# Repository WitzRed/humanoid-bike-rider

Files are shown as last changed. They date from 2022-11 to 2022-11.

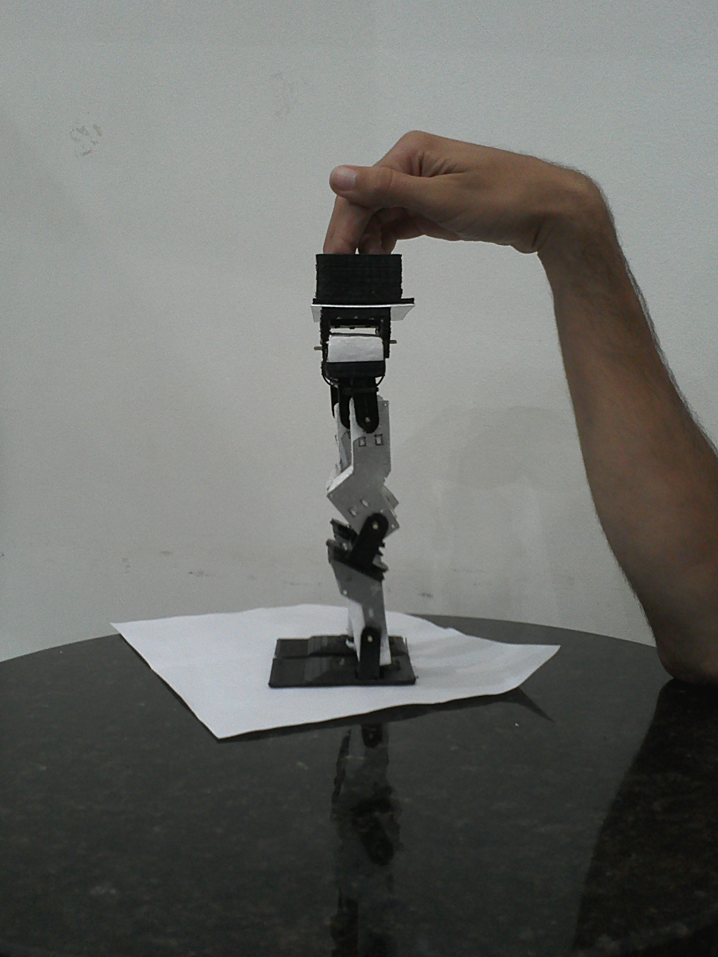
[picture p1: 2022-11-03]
src/paper/assets/CAM00465.jpg

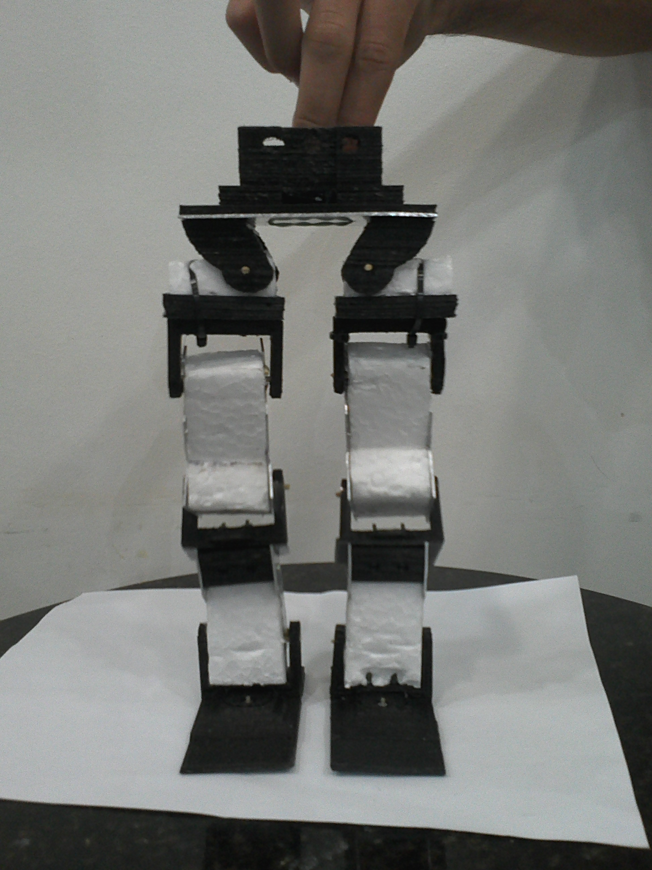
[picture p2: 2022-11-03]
src/paper/assets/CAM00467.jpg

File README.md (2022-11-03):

# humanoid-bike-rider
This project Includes the materials create for the developement of our humanoid bike rider.

https://www.scitepress.org/Papers/2019/77739/77739.pdf

Please use the following citation:

    @inproceedings{
        gorte2019modeling,
        author    = {Jo{\~{a}}o Martin Gorte Jr. and
               Witenberg Santiago Rodrigues Souza and
               Artur Benevenutto Coelho and
               L{\'{\i}} Exequiel E. L{\'{o}}pez},
          editor    = {Oleg Gusikhin and
               Kurosh Madani and
               Janan Zaytoon}, 
          title     = {The Modeling, Construction and Test Process of a 3D Printable Smart
               Robot Rider},  
          booktitle = {Proceedings of the 16th International Conference on Informatics in
               Control, Automation and Robotics, {ICINCO} 2019 - Volume 1, Prague,
               Czech Republic, July 29-31, 2019},   
          pages     = {165--172},
          publisher = {SciTePress},
          year      = {2019},
          url       = {https://doi.org/10.5220/0007773901650172},
          doi       = {10.5220/0007773901650172}
    }

Check out our demonstraion videos:

3D Prinable Humanoid Rider #1
https://www.youtube.com/watch?v=2ANicbNcGmM

First time testing 3D Printable Humanoid Rider #2
https://www.youtube.com/watch?v=PAA-fIjbb9Q

Testing 3D Printable Humanoid Rider #3
https://www.youtube.com/watch?v=QIu-1OhEkto

We thank "Dr. Guero" for his great insights:
https://www.youtube.com/user/DrGuero2001

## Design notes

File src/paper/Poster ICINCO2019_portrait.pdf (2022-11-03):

# The Modeling, Construction and Test Process of a 3D Printable Smart Robot Rider

# João Martin Gorte Jr.¹, Witenberg Santiago Rodrigues Souza

2

# , Artur Benevenutto Coelho

# 3 and Lí Exequiel E. López

3
1Department of Electrical Engineering, Higher Education Institute of Brasilia, L2 Sul, Brasilia, Brazil

# 2Postgraduate Program in Mechatronic Systems, University of Brasilia, Brasilia, Brazil

3Department of Computer Engineering, Higher Education Institute of Brasilia, Brasilia, Brazil

# {xrjunior, wittenberg.rsg}@gmail.com, artur-bc@hotmail.com, lopez@iesb.br

Methodology

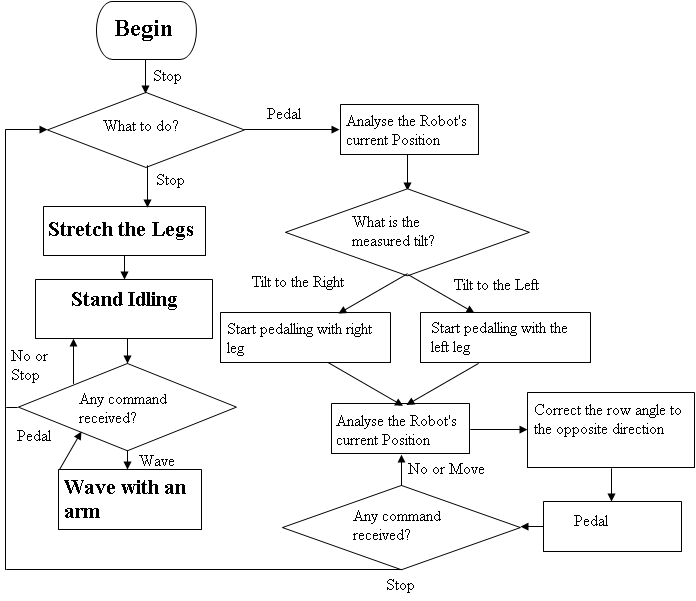
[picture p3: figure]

Results

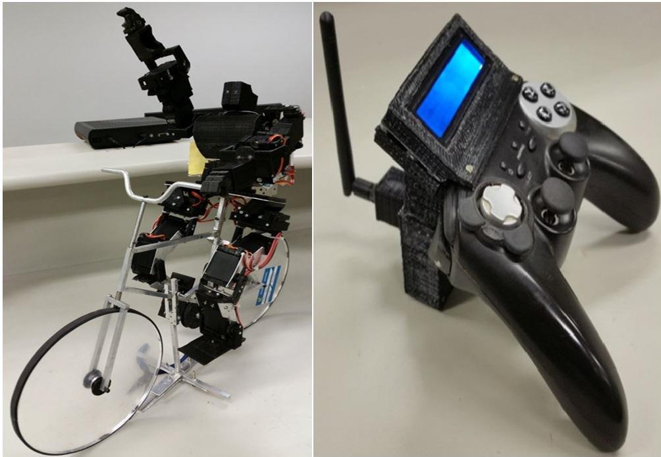
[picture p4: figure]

Conclusion

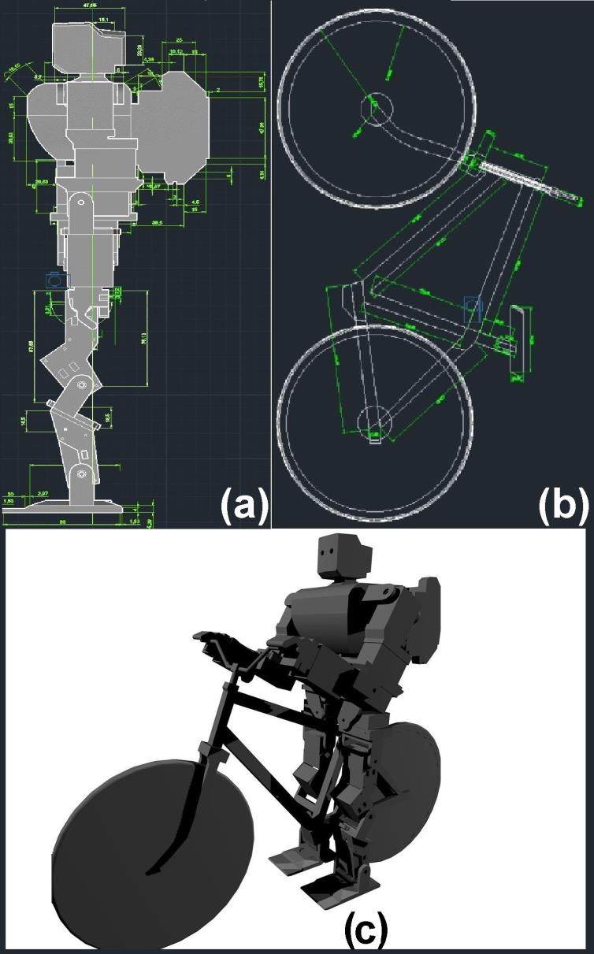
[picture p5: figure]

Introduction

Acknowledgments

Abstract
This work aims to present a modeling procedure, manufacturing process, electronic design, programming and communication system of a cyclist robot. The robot rider has the ability to ride a bicycle independently by making decisions on shifts in balance that may occur during its motion by correcting its direction, balance adjust, and stop. Robot decision-making processes were embedded in a shared control system of interactions with the external environment by commands sent through wired serial link or radio frequency (RF), allowing arm and leg- movements. This
was | achieved | using | a | dual | board
synchronization | powered | by | Atmel
microcontrollers (Arduino) and fed by information from an electronic gyroscope sensor, an accelerometer, and remote radio frequency (RF) receptor. The final prototype was able to pedal from inertia accelerating gradually to its full speed, stop the movement, and move its arms to recover balance.

The possibilities of autonomous bicycles and self-controlled or shared controlled robots able to maneuver vehicles have been explored for years (Getz and Marsden, 1995; Buss, 2000). It can be considered a theme driven by urban mobility needs, reduction of human physical effort and aiding people with disabilities. Moreover, modern urban mobility demands echo applications also motivate the green solution for living in large cities. Thus, increasing capacity of robots moving similarly to humans is essential for this purpose.

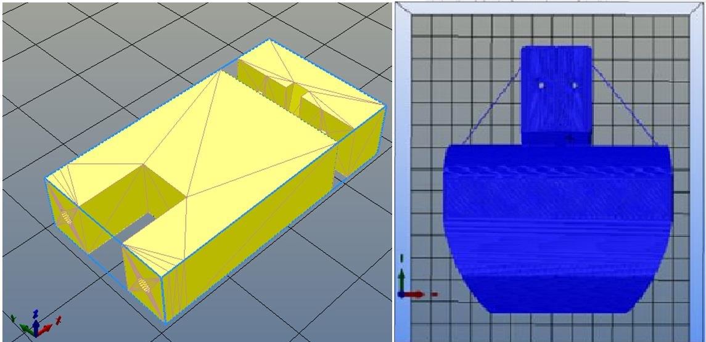
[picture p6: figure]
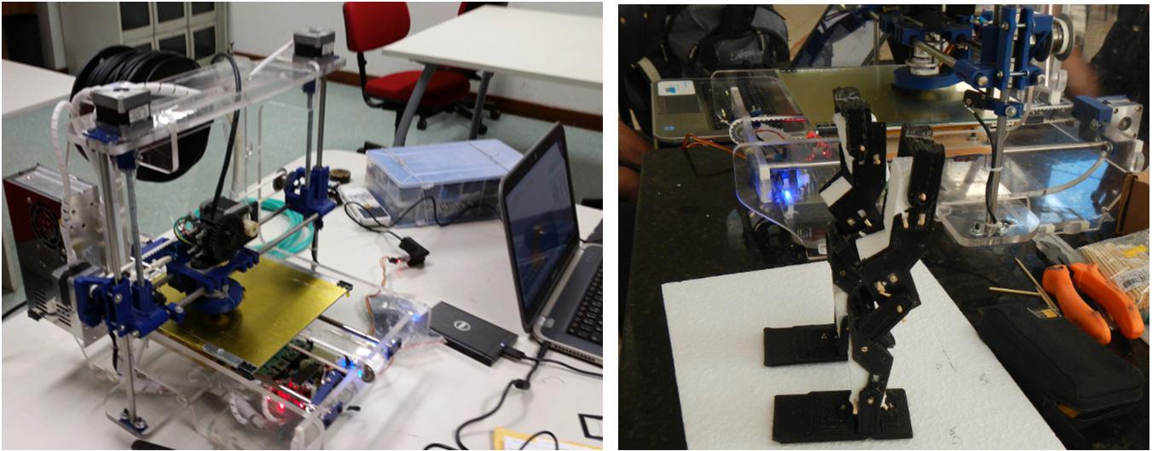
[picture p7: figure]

One of the main goals in Robotics is the automation of tasks done by men (Pazos, 2013). Thus, one of the goals in the field of Robotics is to perform simulation of variety of movements,
decision | making, | hence | human | tasks
performance. Despite intense research activity, large scale implementation of such tasks for daily life routine were not feasible in the early robotics, due to high cost and early development of auxiliary technology, causing to the field a moderate development outside of industrial applications.

Moreover, development of such robotic systems a requires multidisciplinary knowledge. This
work | involved | mathematical | modeling,
mechanical drawing, manufacture techniques in 3D printing, electronic design, micro-controller programming (Arduino, 2015; Banzi, 2013) as well as access to auxiliary devices including gyroscope, accelerometer, and RF system.

Simulation and Tests
Legs were tested to check their movement while pedaling. Tests had shown a balanced structure and well synchronized servomotors. After first tests, current measurements had shown consumption of 1.2A for each leg, in which every servomotor consumed 400mA. On a standby state the robot consumed 370mA. The first pedaling movement had to have fine tuning on tilt coupling, angular speed on each servomotor and low rotation setup to perform the desired movement.

This work presented the process of modeling, design, construction and test of 3D printable robot rider. The algorithm developed in C++ enable robot to move its arms and legs to perform desired actions such as pedaling, turning direction bar, start, and stop movements. The mathematical model proved to reach the proposed movement, although it required fine tuning to smooth the movement. All parts of the bike rider were designed to fit the servomotors. In order to a better performance, a second Arduino board had to be added to split the movements from legs to arms. Future work will include a free run test without a tripod that supported the initial test of the robot. Moreover, a forward kinematic system based on neural network can also be compared to the current algorithm.

The authors would like to thank the Institutional
Program | for | Initiation | in | Technological
Development and Innovation scholarship (PIBITI-CNPq) and the Scientific Initiation Program at the Higher Education Institute of Brasilia- IESB. The authors also would like to thank Dr. Masahiko Yamaguchi (Dr. Guero) and Christina Driessen for their wonderful ideas.

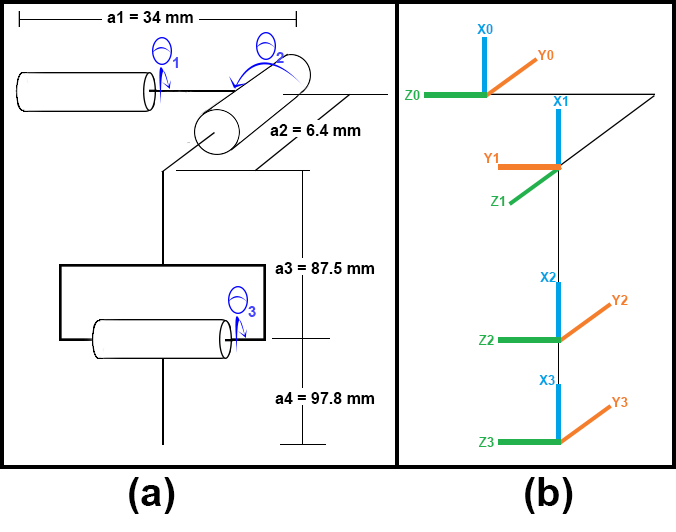
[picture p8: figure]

The algorithm cost required two Arduino boards (salver and master) to split the legs routines from the signals to the arms. A status signal allows the master to know if the other Arduino is on stop mode, movement, or whether an error occurred. Moreover, the master board also receives the remote commands from the joystick. When the system is ready, the master Arduino set all initial parameters on the slaver board to avoid code redundancy. After all parameters set, the slaver board flags back a ready signal to the master board.

The communication between both Arduinos allows the master to send stimuli signals to the slaver board when it is in movement mode. When it is in stop mode however, the master board sends only one stop signal. If the master board stops working and the salver board is in movement mode, as it will not receive the next stimuli, the emergency mode will be triggered when the time for the next stimulus is over. On the other hand, if the slaver Arduino board stops working, the master board will notice it by the status signal as it stopped receiving from the salver board. Therefore, the master board will immediately reset its own status and will keep trying to reestablish the link with the other board until it succeed. After reestablishing the link, the master board sends again the initial parameters to the salver board.

Assembled Final Prototype
The assembled prototype is shown on Figure 7. All 3D printed parts are in black as well as the servomotors. The bicycle is mainly made of aluminum bars and the wheels are made of acrylic. Next to the robot is the RF controller which was partially manufactured in the 3D printer. The controller is used to send the commands to set which movements the robot must perform.

The initial phase was the creation of mathematical models for arms and legs. The final step involved the simulation of movements for arms and legs as well as the first real world test for a pedal movement and balance. The construction of the robot was designed upon the use of renewable materials such as plastic which reduced the manufacturing cost. The same plastic was also used to built the 3D printer which has refurbished pass-motors. Moreover, discarded pieces of aluminum compose the frame of the bicycle and
the side shields on the legs of the robot.

Figure 1: Arm kinematic diagram: (a) link lengths in mm (a1 to a4) and rotation angles, b) four rotation frames for each actuator.

Figure | 2: | Leg | kinematic
diagram: c) link lengths and rotation angles, d) rotation frames.

Figure 4: Parts in the printing process servo’s socket on the left and the slicing process on the right.

Figure 3: Robot
(a) and its bicycle
(b) both sketched in AutoCAD,
(c) 3D model.

Modeling each 3D Part

Figure 5: Algorithm’s flowchart demonstrating the decision steps the robot may take.

Process of 3D printing

The majority of the parts of the robot (approximately 70%) were made by 3D printing. The 3D printers were also assembled using reusable materials. It works with plastic wires (3 mm or 1.75mm) made of polylactic acid (PLA) which is melted to make the layers of the 3D printed parts. After every part was finished by the printer, it was measured in order to check if its dimensions would met the designed project. Symmetry, and layer size were measured. Some parts which should be coupled to servomotor had density increased by 90% in order to bear forces applied to them. Other parts were redesigned for their size were not feasible to be printed as a single piece or they had inner connections that would not able accessed such as chest, battery case, and head). Because of lack of precision for small parts, some parts had to be adapted, such as the hands.

Figure 6: Printer and the first prototype printed legs.

The Assembling Process
A total 15 servo motors of 13N each with were used to move all members of the robot. This phase involved 40% of the project budget. The servo motor were also disassembled to add a 3mm steel axis to the opposite side the servo axis.

The bicycle assembling
In the process of construction of the bicycle, we used a 5mm solid aluminum bar to let the robot lighter and balance the weight / power ratio. TIG welding was used to reinforce the frame and with center of gravity for the suitable robot. The wheels are made of acrylic of 10 mm which were cut using the laser process to stay closer to the CAD model. After the assembling phase was complete, the prototype, as well as its remote control, as shown in 7, were ready for testing.

Figure 8: Foot movement simulation based on hip-to-foot displacement vector.

Figure 9: Movement for the palm of the hand resulted from the transformation by shoulder-to-hand displacement vector.

Figure 7: Assembled robot (second prototype) and joystick remote control.

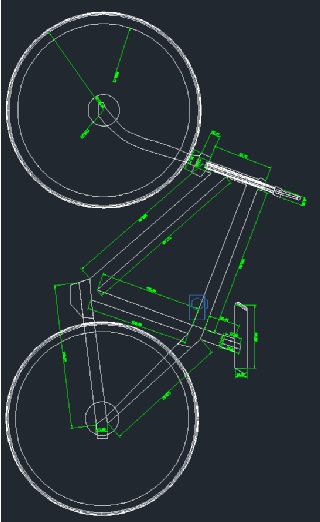
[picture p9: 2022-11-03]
src/paper/assets/bicycle2D.jpg

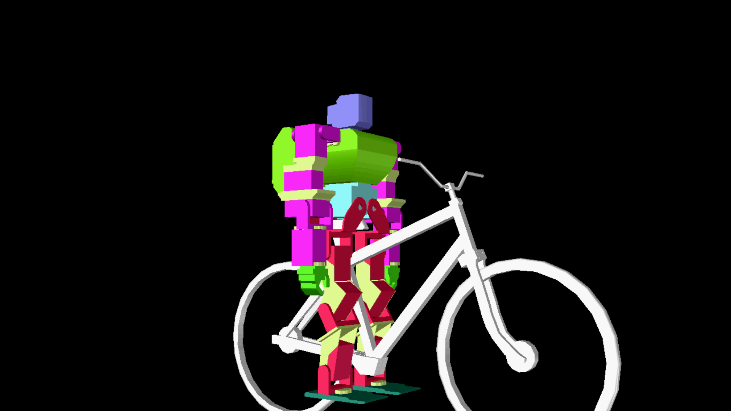
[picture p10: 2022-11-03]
src/paper/assets/robo_de_bike.png

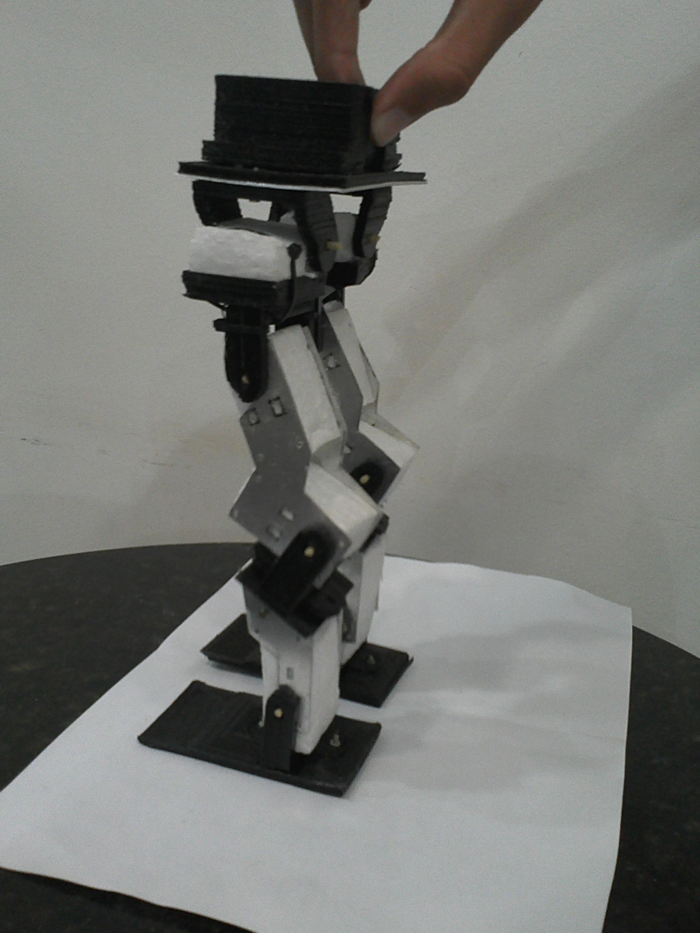
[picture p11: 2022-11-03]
src/paper/assets/CAM00469.jpg

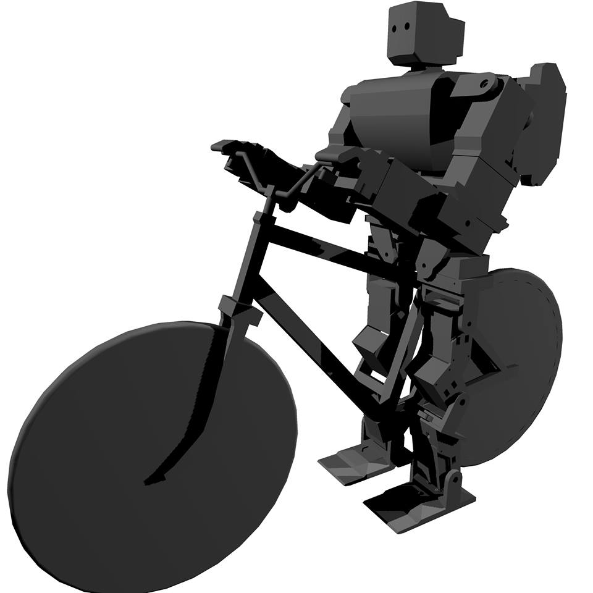
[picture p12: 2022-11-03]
src/paper/assets/Robot.jpg

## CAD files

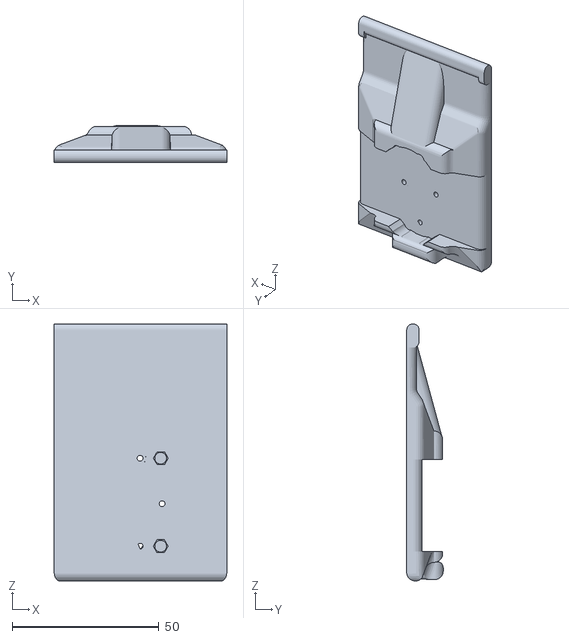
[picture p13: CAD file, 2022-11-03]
src/3d-modeling/DWG_PROJECT/novoPE.stl
58.8 x 12.5 x 87.6

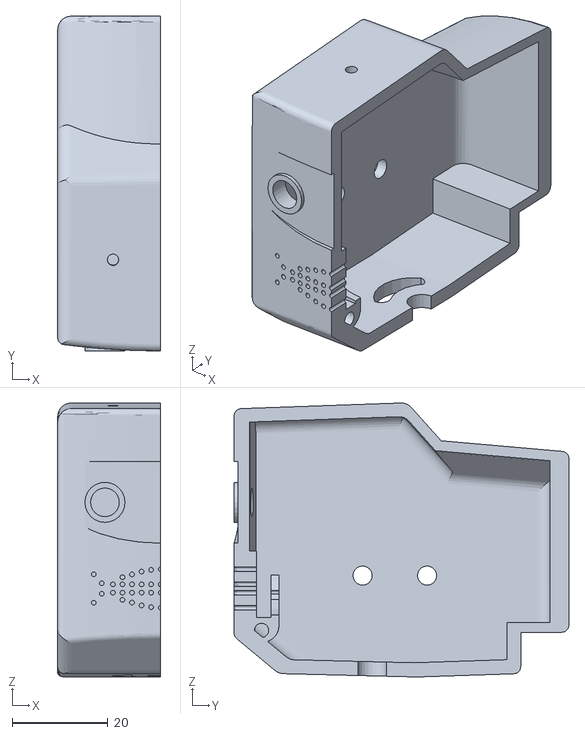
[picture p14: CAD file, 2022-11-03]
src/3d-modeling/DWG_PROJECT/ROBOT_v2017/AUTOCAD/RIGHT_HEAD_ROBOT_RIDER_07_5_2017.stl
21.5 x 70.1 x 57.4

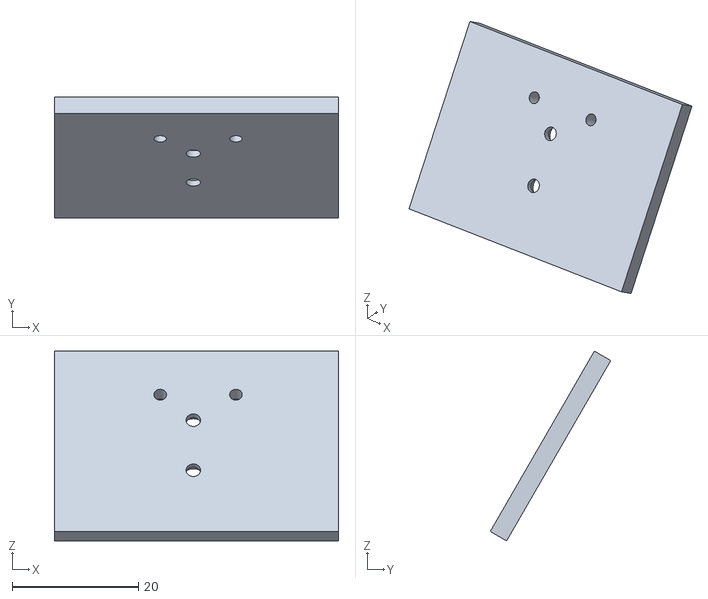
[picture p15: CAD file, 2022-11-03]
src/3d-printing/PARTS_STL/ACRYLIC_KNEE.stl
45.0 x 19.1 x 30.1

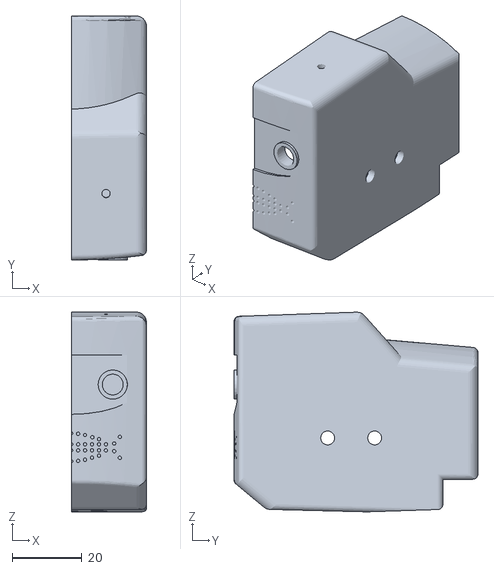
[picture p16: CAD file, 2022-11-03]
src/3d-modeling/DWG_PROJECT/ROBOT_v2017/AUTOCAD/LEFT_HEAD_ROBOT_RIDER__07_5_2017.stl
21.5 x 70.1 x 57.4

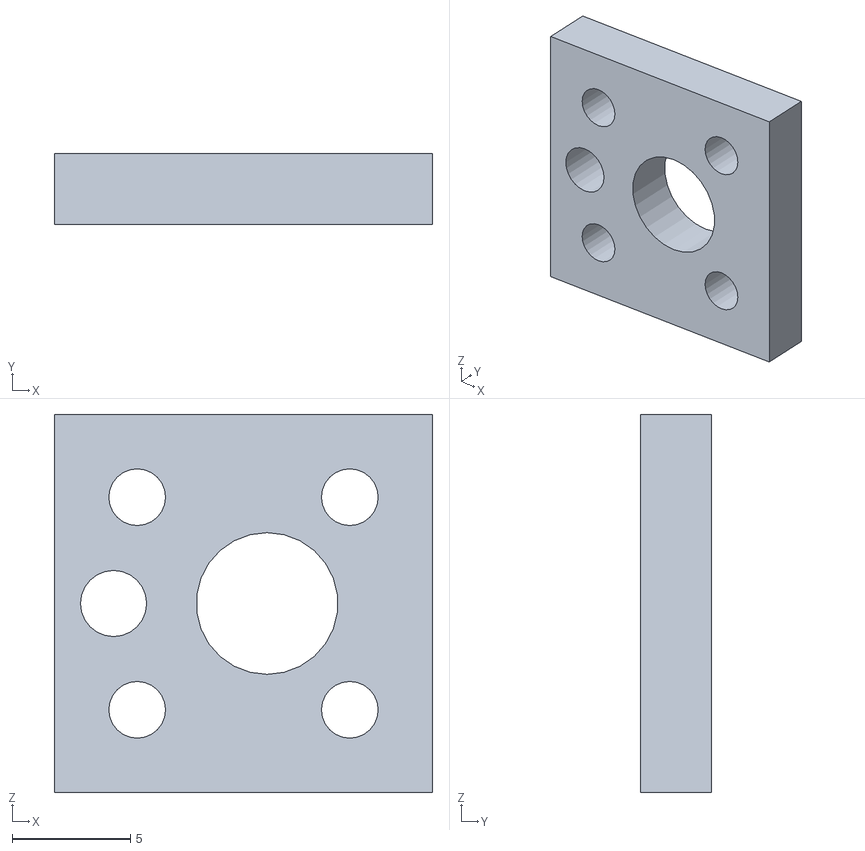
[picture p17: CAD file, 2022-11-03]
src/3d-printing/PARTS_STL/NECK.stl
16.0 x 3.00 x 16.0

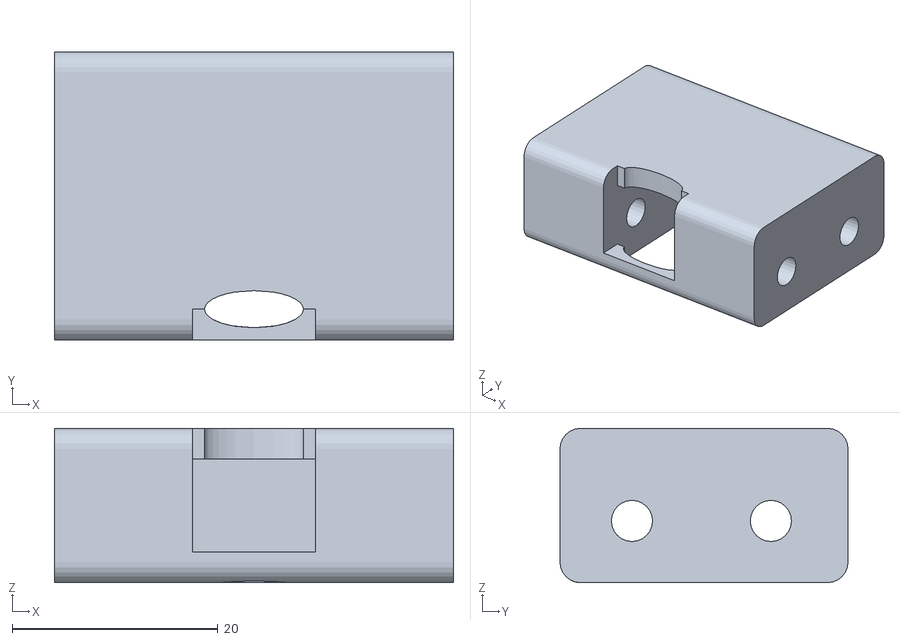
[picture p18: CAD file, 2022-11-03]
src/3d-modeling/DWG_PROJECT/ROBOT_v2017/AUTOCAD/SUPPORT_HEAD_ROBOT_RIDER_07_5_2017.stl
38.8 x 28.0 x 15.0

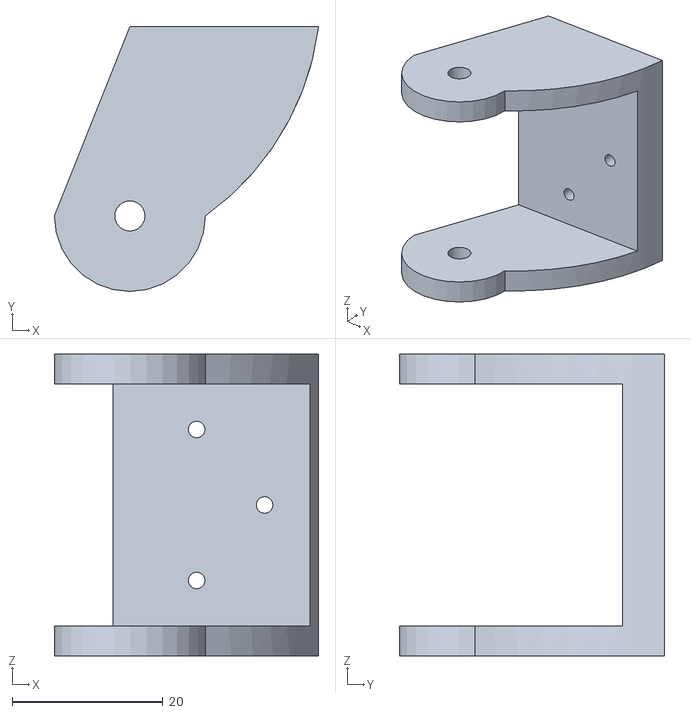
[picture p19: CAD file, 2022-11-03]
src/3d-printing/PARTS_STL/BEARING_HIPS.stl
35.0 x 35.1 x 40.0

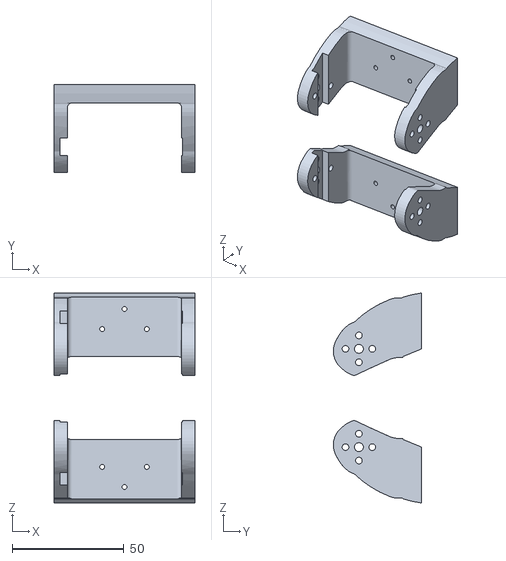
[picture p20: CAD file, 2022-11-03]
src/3d-modeling/DWG_PROJECT/HIPS_LEFT_RIGHT.stl
63.0 x 39.5 x 94.0

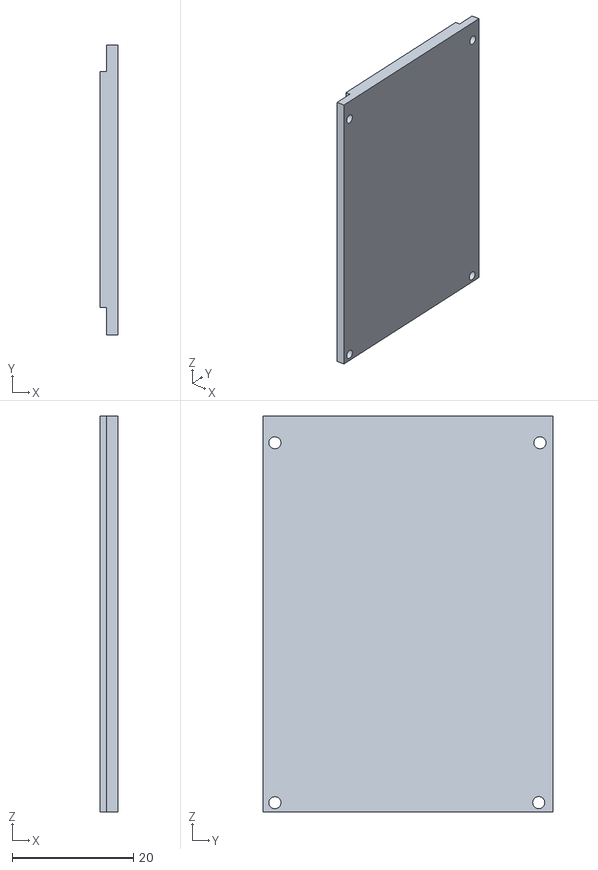
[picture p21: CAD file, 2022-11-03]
src/3d-printing/PARTS_STL/COVER_BAT_D.stl
3.01 x 48.0 x 65.4

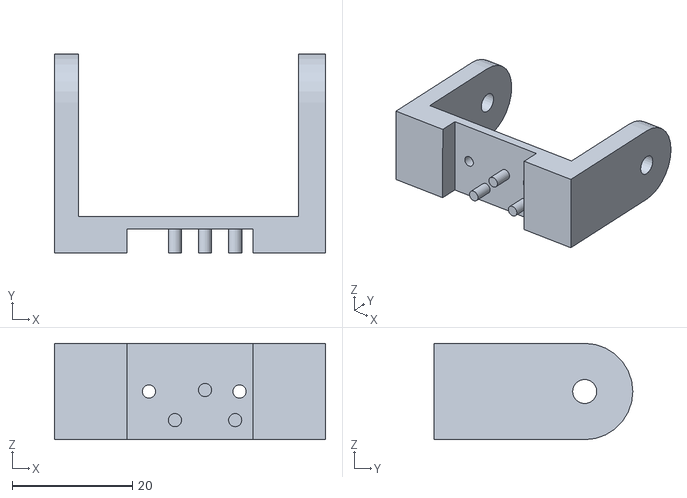
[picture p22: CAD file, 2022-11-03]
src/3d-printing/PARTS_STL/BEARING_ELBOW.stl
45.0 x 33.0 x 16.0

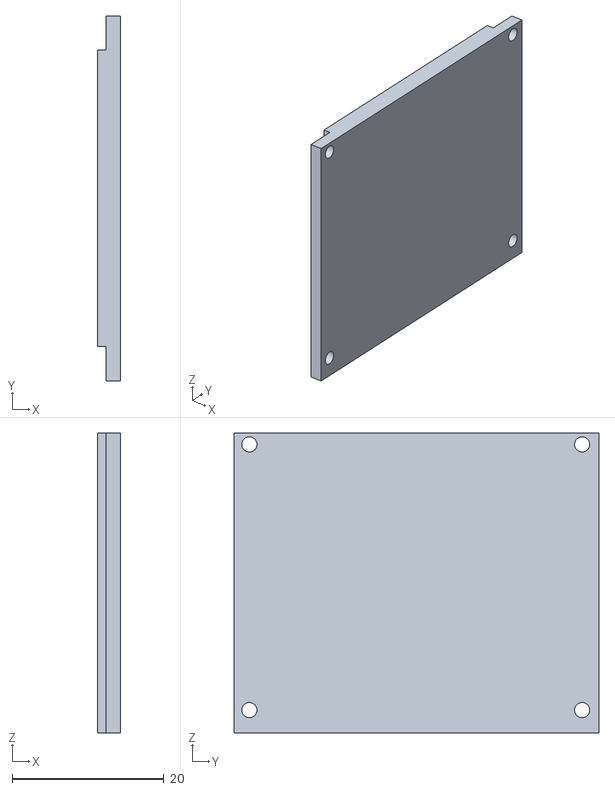
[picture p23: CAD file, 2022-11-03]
src/3d-printing/PARTS_STL/COVER_BAT_E.stl
3.01 x 48.0 x 39.5

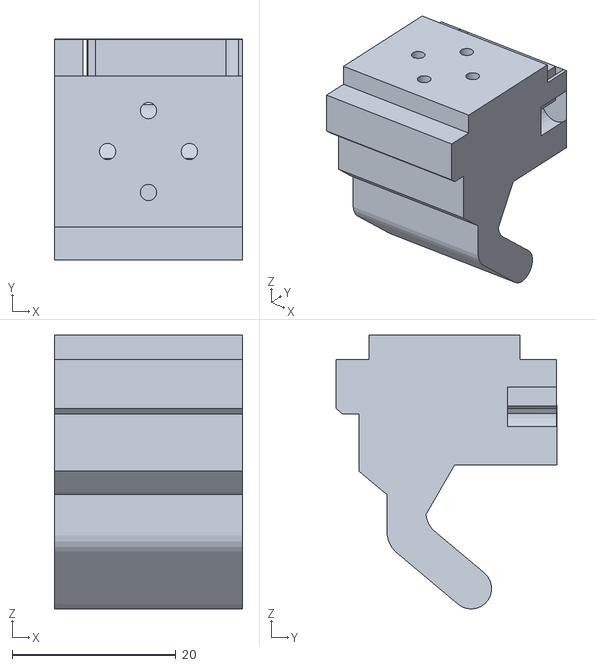
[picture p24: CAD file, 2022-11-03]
src/3d-printing/PARTS_STL/HAND1.stl
23.0 x 27.0 x 33.5

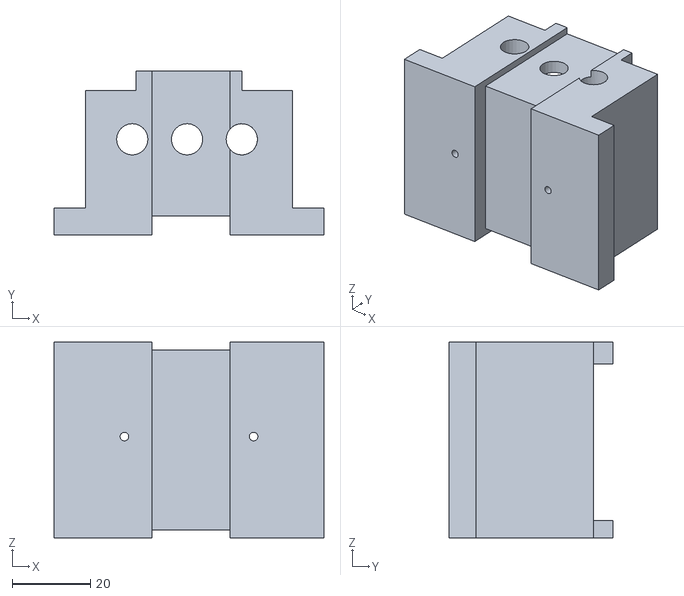
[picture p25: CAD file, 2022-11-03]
src/3d-printing/PARTS_STL/WAIST.stl
69.0 x 42.0 x 50.0

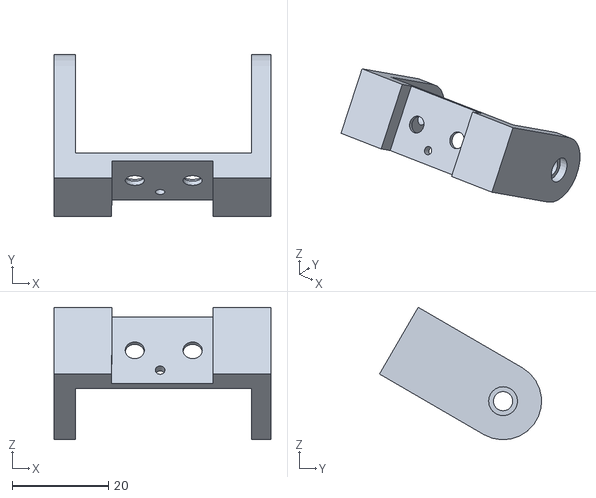
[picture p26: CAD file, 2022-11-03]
src/3d-printing/PARTS_STL/BEARING_KNEE.stl
45.0 x 33.6 x 27.5

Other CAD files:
src/3d-modeling/DWG_PROJECT/Robot_Cyclist_artistic-MSI-WITENBERG.dwg
src/3d-modeling/DWG_PROJECT/Robot_Cyclist.dwg
src/3d-modeling/DWG_PROJECT/Robot_Cyclist_artistic.dwg
src/3d-printing/PARTS_STL/BACK.stl
src/3d-printing/PARTS_STL/BASE_ELBOW.stl
src/3d-printing/PARTS_STL/BASE_FOOT.stl
src/3d-printing/PARTS_STL/BASE_HIP.stl
src/3d-printing/PARTS_STL/BASE_KNEE.stl
src/3d-printing/PARTS_STL/BASE_NECK.stl
src/3d-printing/PARTS_STL/BATTERY_D.stl
src/3d-printing/PARTS_STL/BATTERY_E.stl
src/3d-printing/PARTS_STL/BEARING_ANKLE.stl
src/3d-printing/PARTS_STL/BEARING_THIGH.stl
src/3d-printing/PARTS_STL/BRACKET_WAIST.stl
src/3d-printing/PARTS_STL/CHEST.stl
src/3d-printing/PARTS_STL/CHIN.stl
src/3d-printing/PARTS_STL/FINGER1.stl
src/3d-printing/PARTS_STL/FINGER2.stl
src/3d-printing/PARTS_STL/FOOT_1.stl
src/3d-printing/PARTS_STL/FOOT_2.stl
src/3d-printing/PARTS_STL/FOREARM.stl
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

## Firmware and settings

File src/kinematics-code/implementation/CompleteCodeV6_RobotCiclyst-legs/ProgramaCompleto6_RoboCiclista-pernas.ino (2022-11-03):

// Algorítimo principal
#include<avr/wdt.h>
#include<I2Cdev.h>
#include<Wire.h>
#include<Servo.h>
#include "config.h"
#include "variaveis.h"
#include "movimentos.h"
#include "parada.h"
#include "pedalada.h"

void setup() {
  // put your setup code here, to run once:
  Wire.begin(1);
  Wire.onReceive(SinalRecebido); // register event
  Serial.begin(9600);
  
  wdt_enable(WDTO_4S);
  
  servoQuadrilE.attach(ServoQuadrilE_Porta);
  servoCoxaE.attach(ServoCoxaE_Porta);
  servoJoelhoE.attach(ServoJoelhoE_Porta);
  servoTornozeloE.attach(ServoTornozeloE_Porta);
  servoQuadrilD.attach(ServoQuadrilD_Porta);
  servoCoxaD.attach(ServoCoxaD_Porta);
  servoJoelhoD.attach(ServoJoelhoD_Porta);
  servoTornozeloD.attach(ServoTornozeloD_Porta);
  pinMode(LED_Porta, OUTPUT);
  pinMode(Reset_Porta, OUTPUT);
  
  
  digitalWrite(Reset_Porta, LOW);
}

void loop() {
  // put your main code here, to run repeatedly:
  if(iniciando != -1) {
    digitalWrite(Reset_Porta, HIGH);
    switch(estado) {
      case 1: // Pedalar
        digitalWrite(LED_Porta, HIGH);
        if(ciclo == -1) {
          Inicializar();
          Ajuste_Pernas(1);
          
          if(Tipo_Pedalada == 1) {
            PernaE = PernaE_Habilitada;
            PernaD = 0;
            Mexer_Pernas(1);
            
            delay(Delay_Quadril);
            Mexer_Quadril();
          } else {
            PernaE = 0;
            PernaD = PernaD_Habilitada;
            Mexer_Pernas(1);
            
            delay(Delay_Quadril);
            Mexer_Quadril();
          }
          
          delay(Delay_Ajuste);
          Ajuste_Pernas(0);
        }
        ciclo++;
        
        if((ciclo%Delay_Servos) == 0) {
          if(Pedalar_Ligado == 1) {
            if(iniciando == 1) {
              if(Tipo_Pedalada == 1) {
                PernaE = 0;
                if(sentidoCoxas == 1) {
                  posCoxaD += (InicioPedalada_CoxaD);
                  posJoelhoD -= (InicioPedalada_JoelhoD);
                  posTornozeloD -= (InicioPedalada_TornozeloD);
                  
                  PernaE = PernaE_Habilitada;
                  PernaD = PernaD_Habilitada;
                  Mexer_Pernas(1);
                  
                  posCoxaD -= (InicioPedalada_CoxaD);
                  posJoelhoD += (InicioPedalada_JoelhoD);
                  posTornozeloD += (InicioPedalada_TornozeloD);
                  
                  Mexer_Quadril();
                  
                  iniciando = 0;
                }
                
              } else {
                PernaD = 0;
                if(sentidoCoxas == 0) {
                  posCoxaE -= (InicioPedalada_CoxaE);
                  posJoelhoE += (InicioPedalada_JoelhoE);
                  posTornozeloE += (InicioPedalada_TornozeloE);
                  
                  PernaE = PernaE_Habilitada;
                  PernaD = PernaD_Habilitada;
                  Mexer_Pernas(1);
                  
                  posCoxaE += (InicioPedalada_CoxaE);
                  posJoelhoE -= (InicioPedalada_JoelhoE);
                  posTornozeloE -= (InicioPedalada_TornozeloE);
                  
                  Mexer_Quadril();
                  
                  iniciando = 0;
                }
              }
            }
            Pedalar();
            if(Delay_Servos > Delay_Servos_Min) {
              Delay_Servos -= Delay_Servos_Taxa;
              Ciclos_Ref = Delay_Servos*Taxa_Ref;
            }
          }
          
          Mexer_Pernas(1);
        
        }
        break;
      
      case 3: // Parada de Emergencia
        Parada_Emergencia();
        break;
      
      default: // Parar
        digitalWrite(LED_Porta, LOW);
        if(x == 200)
          iniciando = -1;
    
        if(Delay_Servos < Delay_Servos_Max) {
          ciclo++;
          
          if((ciclo%Delay_Servos) == 0) {
            if(Pedalar_Ligado == 1) {
              Pedalar();
              Delay_Servos += Delay_Servos_Taxa*2;
              Ciclos_Ref = Delay_Servos*Taxa_Ref;
              ciclo = 1;
              
              if(posJoelhoE < ServoJoelhoE_Meio) {
                Tipo_Pedalada = 1;
              } else {
                Tipo_Pedalada = 0;
              }
            }
            PernaE = PernaE_Habilitada;
            PernaD = PernaD_Habilitada;
            Mexer_Pernas(1);
          }
        } else if(ciclo != 0) {
          Delay_Servos = Delay_Servos_Max;
          
          if((posJoelhoE < ServoJoelhoE_Max) && (posJoelhoE > ServoJoelhoE_Min)){
            if(posJoelhoE < ServoJoelhoE_Meio) {
              Inicio_Pedalada();
              PernaE = 0;
              PernaD = PernaD_Habilitada;
              Mexer_Quadril();
              Mexer_Pernas(1);
            } else {
              Inicio_Pedalada();
              PernaE = PernaE_Habilitada;
              PernaD = 0;
              Mexer_Quadril();
              Mexer_Pernas(1);
            }
            delay(Delay_Ajuste);
          }
          
          Ciclos_Ref = Delay_Servos*Taxa_Ref;
          Parar();
          
          PernaE = PernaE_Habilitada;
          PernaD = PernaD_Habilitada;
          Mexer_Quadril();
          delay(Delay_Quadril);
          Mexer_Pernas(0);
          ciclo = 0;
        }
        break;
    }
        
    if(ciclo >= Ciclos_Ref) {
      ciclo = 1;
    }
    
    if(Delay_Servos < Delay_Servos_Min) {
      Delay_Servos = Delay_Servos_Min;
    }
    
    if(Delay_Servos > Delay_Servos_Max) {
      Delay_Servos = Delay_Servos_Max;
    }
  }
  
  delay(1);
  
  wdt_reset();
}

void SinalRecebido(int Quanto) {
  if(iniciando != -1) {
    while(Wire.available()){
      receptor = Wire.read();
    }
      
    estado = receptor;
    
    if(estado >= 50 || estado < 0) {
      iniciando = -1;
      estado = 0;
    } else {
      Serial.print("Estado: ");
      Serial.println(estado);
    }
  } else {
    x = Wire.read();
    Serial.print("x = ");
    Serial.println(x);
    switch(x) {
      case 0:
        digitalWrite(Reset_Porta, HIGH);
        PernaE_Habilitada = Wire.read();
        Serial.println(PernaE_Habilitada);
        break;
      
      case 1:
        PernaD_Habilitada = Wire.read();
        Serial.println(PernaD_Habilitada);
        break;
      
      case 2:
        Pedalar_Ligado = Wire.read();
        Serial.println(Pedalar_Ligado);
        break;
      
      case 3:
        Tipo_Pedalada = Wire.read();
        Serial.println(Tipo_Pedalada);
        break;
      
      case 4:
        SentidoCoxas_Iguais = Wire.read();
        Serial.println(SentidoCoxas_Iguais);
        break;
      
      case 5:
        SentidoJoelhos_Iguais = Wire.read();
        Serial.println(SentidoJoelhos_Iguais);
        break;
      
      case 6:
        SentidoTornozelos_Iguais = Wire.read();
        Serial.println(SentidoTornozelos_Iguais);
        break;
      
      case 7:
        sinalX = Wire.read();
        QuadrilE_Desvio = Wire.read();
        
        if(sinalX == '-')
          QuadrilE_Desvio = QuadrilE_Desvio * (-1);
        
        Serial.println(QuadrilE_Desvio);
        break;
      
      case 8:
        sinalX = Wire.read();
        QuadrilD_Desvio = Wire.read();
        
        if(sinalX == '-')
          QuadrilD_Desvio = QuadrilD_Desvio * (-1);
        
        
        Serial.println(QuadrilD_Desvio);
        break;
      
      case 9:
        sinalX = Wire.read();
        CoxaE_Desvio = Wire.read();
        
        if(sinalX == '-')
          CoxaE_Desvio = CoxaE_Desvio * (-1);
        
        
        Serial.println(CoxaE_Desvio);
        break;
      
      case 10:
        sinalX = Wire.read();
        CoxaD_Desvio = Wire.read();
        
        if(sinalX == '-')
          CoxaD_Desvio = CoxaD_Desvio * (-1);
        
        
        Serial.println(CoxaD_Desvio);
        break;
      
      case 11:
        sinalX = Wire.read();
        JoelhoE_Desvio = Wire.read();
        
        if(sinalX == '-')
          JoelhoE_Desvio = JoelhoE_Desvio * (-1);
        
        
        Serial.println(JoelhoE_Desvio);
        break;
      
      case 12:
        sinalX = Wire.read();
        JoelhoD_Desvio = Wire.read();
        
        if(sinalX == '-')
          JoelhoD_Desvio = JoelhoD_Desvio * (-1);
        
        
        Serial.println(JoelhoD_Desvio);
        break;
      
      case 13:
        sinalX = Wire.read();
        TornozeloE_Desvio = Wire.read();
        
        if(sinalX == '-')
          TornozeloE_Desvio = TornozeloE_Desvio * (-1);
        
        
        Serial.println(TornozeloE_Desvio);
        break;
      
      case 14:
        sinalX = Wire.read();
        TornozeloD_Desvio = Wire.read();
        
        if(sinalX == '-')
          TornozeloD_Desvio = TornozeloD_Desvio * (-1);
        
        
        Serial.println(TornozeloD_Desvio);
        break;
      
      case 15:
        Altura_Ajuste = Wire.read();
        Serial.println(Altura_Ajuste);
        break;
      
      case 16:
        InicioPedalada_CoxaE = Wire.read();
        Serial.println(InicioPedalada_CoxaE);
        break;
      
      case 17:
        InicioPedalada_JoelhoE = Wire.read();
        Serial.println(InicioPedalada_JoelhoE);
        break;
      
      case 18:
        InicioPedalada_TornozeloE = Wire.read();
        Serial.println(InicioPedalada_TornozeloE);
        break;
      
      case 19:
        InicioPedalada_CoxaD = Wire.read();
        Serial.println(InicioPedalada_CoxaD);
        break;
      
      case 20:
        InicioPedalada_JoelhoD = Wire.read();
        Serial.println(InicioPedalada_JoelhoD);
        break;
      
      case 21:
        InicioPedalada_TornozeloD = Wire.read();
        Serial.println(InicioPedalada_TornozeloD);
        break;
      
      case 22:
        Delay_Servos_Max = Wire.read();
        Serial.println(Delay_Servos_Max);
        break;
      
      case 23:
        Delay_Servos_Min = Wire.read();
        Serial.println(Delay_Servos_Min);
        break;
      
      case 24:
        Delay_Servos = Wire.read();
        Serial.println(Delay_Servos);
        break;
      
      case 25:
        Delay_Servos_Taxa = Wire.read();
        Serial.println(Delay_Servos_Taxa);
        break;
      
      case 26:
        Delay_Pausa = Wire.read();
        Delay_Pausa = Delay_Pausa*10;
        Serial.println(Delay_Pausa);
        break;
      
      case 27:
        Delay_Quadril = Wire.read();
        Delay_Quadril = Delay_Quadril*10;
        Serial.println(Delay_Quadril);
        break;
      
      case 28:
        Delay_Ajuste = Wire.read();
        Serial.println(Delay_Ajuste);
        break;
      
      case 29:
        TaxaMax_Ref = Wire.read();
        Serial.println(TaxaMax_Ref);
        break;
      
      case 30:
        TaxaMin_Ref = Wire.read();
        Serial.println(TaxaMin_Ref);
        break;
      
      case 31:
        Taxa_Ref = Wire.read();
        Serial.println(Taxa_Ref);
        break;
      
      case 32:
        Parada_QuadrilE = Wire.read();
        Serial.println(Parada_QuadrilE);
        break;
      
      case 33:
        Parada_CoxaE = Wire.read();
        Serial.println(Parada_CoxaE);
        break;
      
      case 34:
        Parada_JoelhoE = Wire.read();
        Serial.println(Parada_JoelhoE);
        break;
      
      case 35:
        Parada_TornozeloE = Wire.read();
        Serial.println(Parada_TornozeloE);
        break;
      
      case 36:
        Parada_QuadrilD = Wire.read();
        Serial.println(Parada_QuadrilD);
        break;
      
      case 37:
        Parada_CoxaD = Wire.read();
        Serial.println(Parada_CoxaD);
        break;
      
      case 38:
        Parada_JoelhoD = Wire.read();
        Serial.println(Parada_JoelhoD);
        break;
      
      case 39:
        Parada_TornozeloD = Wire.read();
        Serial.println(Parada_TornozeloD);
        break;
      
      case 40:
        Servos_Pos_Max = Wire.read();
        Serial.println(Servos_Pos_Max);
        break;
      
      case 41:
        Servos_Pos_Min = Wire.read();
        Serial.println(Servos_Pos_Min);
        break;
      
      case 42:
        ServoQuadrilE_Pos_Max = Wire.read();
        Serial.println(ServoQuadrilE_Pos_Max);
        break;
      
      case 43:
        ServoQuadrilE_Pos_Min = Wire.read();
        Serial.println(ServoQuadrilE_Pos_Min);
        break;
      
      case 44:
        ServoQuadrilD_Pos_Max = Wire.read();
        Serial.println(ServoQuadrilD_Pos_Max);
        break;
      
      case 45:
        ServoQuadrilD_Pos_Min = Wire.read();
        Serial.println(ServoQuadrilD_Pos_Min);
        break;
      
      case 46:
        ServosQuadris_Raio = Wire.read();
        Serial.println(ServosQuadris_Raio);
        break;
      
      case 47:
        ServosCoxas_Raio = Wire.read();
        Serial.println(ServosCoxas_Raio);
        break;
      
      case 48:
        ServosJoelhos_Raio = Wire.read();
        Serial.println(ServosJoelhos_Raio);
        break;
      
      case 49:
        ServosTornozelos_Raio = Wire.read();
        Serial.println(ServosTornozelos_Raio);
        iniciando = -2;
        break;
      
      default:
        while(Wire.available())
          Wire.read();
    }
  
  }
  
  if(iniciando == -2) {
    Servos_Raio_Ref = (ServosCoxas_Raio + ServosJoelhos_Raio + ServosTornozelos_Raio) / 3;
    ServoQuadrilE_Meio = (90 + QuadrilE_Desvio - 30);
    ServoQuadrilD_Meio = (90 + QuadrilD_Desvio - 49);
    ServoCoxaE_Meio = (90 - CoxaE_Desvio - 19);
    ServoCoxaD_Meio = (90 + CoxaD_Desvio - 44);
    ServoJoelhoE_Meio = (90 + JoelhoE_Desvio + 128);
    ServoJoelhoD_Meio = (90 - JoelhoD_Desvio + 10);
    ServoTornozeloE_Meio = (90 - TornozeloE_Desvio - 20);
    ServoTornozeloD_Meio = (90 + TornozeloD_Desvio + 60);
    Serial.println(Servos_Raio_Ref);
    Serial.println(ServoQuadrilE_Meio);
    Serial.println(ServoQuadrilD_Meio);
    Serial.println(ServoCoxaE_Meio);
    Serial.println(ServoCoxaD_Meio);
    Serial.println(ServoJoelhoE_Meio);
    Serial.println(ServoJoelhoD_Meio);
    Serial.println(ServoTornozeloE_Meio);
    Serial.println(ServoTornozeloD_Meio);
    
    ServoQuadrilE_Max = (ServoQuadrilE_Meio+ServosQuadris_Raio);
    ServoQuadrilE_Min = (ServoQuadrilE_Meio-ServosQuadris_Raio);
    ServoQuadrilD_Max = (ServoQuadrilD_Meio+ServosQuadris_Raio);
    ServoQuadrilD_Min = (ServoQuadrilD_Meio-ServosQuadris_Raio);
    ServoCoxaE_Max = (ServoCoxaE_Meio+ServosCoxas_Raio);
    ServoCoxaE_Min = (ServoCoxaE_Meio-ServosCoxas_Raio);
    ServoCoxaD_Max = (ServoCoxaD_Meio+ServosCoxas_Raio);
    ServoCoxaD_Min = (ServoCoxaD_Meio-ServosCoxas_Raio);
    ServoJoelhoE_Max = (ServoJoelhoE_Meio+ServosJoelhos_Raio);
    ServoJoelhoE_Min = (ServoJoelhoE_Meio-ServosJoelhos_Raio);
    ServoJoelhoD_Max = (ServoJoelhoD_Meio+ServosJoelhos_Raio);
    ServoJoelhoD_Min = (ServoJoelhoD_Meio-ServosJoelhos_Raio);
    ServoTornozeloE_Max = (ServoTornozeloE_Meio+ServosTornozelos_Raio);
    ServoTornozeloE_Min = (ServoTornozeloE_Meio-ServosTornozelos_Raio);
    ServoTornozeloD_Max = (ServoTornozeloD_Meio+ServosTornozelos_Raio);
    ServoTornozeloD_Min = (ServoTornozeloD_Meio-ServosTornozelos_Raio);
    
    Serial.println(ServoQuadrilE_Max);
    Serial.println(ServoQuadrilE_Min);
    Serial.println(ServoQuadrilD_Max);
    Serial.println(ServoQuadrilD_Min);
    Serial.println(ServoCoxaE_Max);
    Serial.println(ServoCoxaE_Min);
    Serial.println(ServoCoxaD_Max);
    Serial.println(ServoCoxaD_Min);
    Serial.println(ServoJoelhoE_Max);
    Serial.println(ServoJoelhoE_Min);
    Serial.println(ServoJoelhoD_Max);
    Serial.println(ServoJoelhoD_Min);
    Serial.println(ServoTornozeloE_Max);
    Serial.println(ServoTornozeloE_Min);
    Serial.println(ServoTornozeloD_Max);
    Serial.println(ServoTornozeloD_Min);
  
    TaxaCoxas_Ref = ServosCoxas_Raio/Servos_Raio_Ref;
    TaxaJoelhos_Ref = ServosJoelhos_Raio/Servos_Raio_Ref;
    TaxaTornozelos_Ref = ServosTornozelos_Raio/Servos_Raio_Ref;
    
    Serial.print(ServosCoxas_Raio);
    Serial.print(" / ");
    Serial.println(Servos_Raio_Ref);
    Serial.println(TaxaCoxas_Ref);
    Serial.print(ServosJoelhos_Raio);
    Serial.print(" / ");
    Serial.println(Servos_Raio_Ref);
    Serial.println(TaxaJoelhos_Ref);
    Serial.print(ServosTornozelos_Raio);
    Serial.print(" / ");
    Serial.println(Servos_Raio_Ref);
    Serial.println(TaxaTornozelos_Ref);
    
    Inicializar();
  }
  
  wdt_reset();
}

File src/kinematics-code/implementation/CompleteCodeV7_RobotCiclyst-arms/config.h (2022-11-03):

// Parâmetros de habilitação/desabilitação e ajustes de membros e procedimentos
#define LogAcelerometro            1 // 0 = Desligado / 1 = Ligado *
#define PernaE_Habilitada          1 // 0 = Desligado / 1 = Ligado *
#define PernaD_Habilitada          1 // 0 = Desligado / 1 = Ligado *
#define BracoE_Habilitados         0 // 0 = Desligado / 1 = Ligado
#define BracoD_Habilitados         0 // 0 = Desligado / 1 = Ligado
#define Remoto_Habilitado          0 // 0 = Desligado / 1 = Ligado
#define Escravo_Ligado             0 // 0 = Falso / 1 = Verdadeiro
#define Botoes_Ligado              0 // 0 = Falso / 1 = Verdadeiro
#define Pedalar_Ligado             1 // 0 = Falso / 1 = Verdadeiro *
#define Auto_Pedalar               1 // 0 = Manual / 1 = Automático
#define Auto_Parar                 0 // 0 = Manual / 1 = Automático
#define Timer_OFF                  15 // Tempo em segundos que o robô irá pedalar contínuamente
#define Timer_ON                   10 // Tempo em segundos que o robô irá ficar parado até começar a pedalar automaticamente

// Parâmetros de configuração de servos e funções
int Tipo_Pedalada = 0; // 0 = Perna direita a frente / 1 = Perna esquerda a frente *
#define SentidoCoxas_Iguais        0 // 0 = Falso / 1 = Verdadeiro *
#define SentidoJoelhos_Iguais      1 // 0 = Falso / 1 = Verdadeiro *
#define SentidoTornozelos_Iguais   1 // 0 = Falso / 1 = Verdadeiro *
#define Bracos_Inicio              1 // 0 = Guidão / 1 = Abertos

// Regulagem do desvio dos servos das pernas para ajustes finos rápidos
#define QuadrilE_Desvio            0 // fora(-)(+)dentro *
#define QuadrilD_Desvio            0 // fora(-)(+)dentro *
#define CoxaE_Desvio               5 // baixo(-)(+)cima *
#define CoxaD_Desvio               33 // baixo(-)(+)cima *
#define JoelhoE_Desvio            -8 // frente(-)(+)traz *
#define JoelhoD_Desvio            -3 // frente(-)(+)traz *
#define TornozeloE_Desvio          0 // baixo(-)(+)cima *
#define TornozeloD_Desvio          0 // baixo(-)(+)cima *

// Ajustes de Movimento
#define Altura_Ajuste              25 // *
#define InicioPedalada_CoxaE       20 // baixo(-)(+)cima *
#define InicioPedalada_JoelhoE     20 // frente(-)(+)traz *
#define InicioPedalada_TornozeloE  20 // baixo(-)(+)cima *
#define InicioPedalada_CoxaD       20 // baixo(-)(+)cima *
#define InicioPedalada_JoelhoD     20 // frente(-)(+)traz *
#define InicioPedalada_TornozeloD  20 // baixo(-)(+)cima *

// Referências de funções, para os potores conseguirem efetuar o movimento esperado
#define Delay_Acelerometro         100
#define Delay_LeituraAnalogica     100
#define Delay_Retransmissao        2 // Tempo em segundos entre as tentativas de reenvio de comando em caso de falha
#define Tentativas                 3
#define Delay_Servos_Max           100 // *
#define Delay_Servos_Min           40 // *
int Delay_Servos = Delay_Servos_Max; // *
#define Delay_Servos_Taxa          1 // *
#define Delay_Pausa                1000 // *
#define Delay_Quadril              850 // *
#define Delay_Ajuste               200 // *
#define Delay_Tchau                500
#define TaxaMax_Ref                8 // *
#define TaxaMin_Ref                4 // *
#define Taxa_Ref                   1 // *
#define Taxa_Tchau                 1

// Constantes de ângulos cujo o robô vá para a posição de parado
#define Parada_QuadrilE            62 // *
#define Parada_CoxaE               130 // *
#define Parada_JoelhoE             15 // *
#define Parada_TornozeloE          155 // *
#define Parada_QuadrilD            45 // *
#define Parada_CoxaD               110 // *
#define Parada_JoelhoD             165 // *
#define Parada_TornozeloD          20 // *

// Regulagem dos desvios dos eixos do acelerômetro para definir o ângulo do robô em equilíbrio
#define EixoAX_Desvio              47
#define EixoAY_Desvio             -61
#define EixoAZ_Desvio             -47
#define Zona_Morta_A               5
#define Zona_Morta_G               5

// Atribuição de portas digitais aos dispositivos
#define ServosOmbroE_Porta         3
#define ServosBracoE_Porta         4
#define ServosCotoveloE_Porta      5
#define ServosOmbroD_Porta         6
#define ServosBracoD_Porta         7
#define ServosCotoveloD_Porta      8
//#define LED_Porta                  13
#define BTN1_Porta                 A0
#define BTN2_Porta                 A1
#define Reset_Porta                A7

// Parâmetros de níveis de leituras das portas analógicas
#define NivelAlto                  768
#define NivelBaixo                 256

// Parâmetros de limites dos servos motores com angulação total disponível
#define Servos_Pos_Max             180 // *
#define Servos_Pos_Min             0 // *
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

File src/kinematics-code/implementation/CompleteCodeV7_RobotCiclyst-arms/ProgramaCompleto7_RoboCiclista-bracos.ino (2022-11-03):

// Algorítimo principal
#include<avr/wdt.h>
#include <SPI.h>
#include "RF24.h"
#include<I2Cdev.h>
#include "MPU6050.h"
#include<Wire.h>
#include<Servo.h>
#include "config.h"
#include "variaveis.h"
#include "movimentos.h"
#include "parada.h"

MPU6050 accelgyro;
RF24 moduloRF(9, 10);

const uint64_t tubo = 0x034f30aaf8LL;

void setup() {
  // put your setup code here, to run once:
  
  Wire.begin();
  
  Serial.begin(9600);
  

  moduloRF.begin();                 //Inicialidando o MÓDULO para comunicação.
  
  moduloRF.setChannel(68);          //Configurando para trabalhar no canal de número 68, 
                                    //ou seja, canal de número 64 em hexadecimal.
  
  moduloRF.startListening();        //Inicializando o MÓDULO para "ouvir" as requisições.
 
  // Mensagem Instrutiva
  Serial.println("Digite A para andar, P para parar e T para acenar");
  Serial.println(" ");
  Serial.println("Log:");
  Serial.println(" ");

  // Inicializando dispositivos
  Serial.println(F("Inicializando dispositivos I2C..."));
  accelgyro.initialize();

  // Testando conexoes
  Serial.println(F("Testando conexoes do dispositivo..."));
  MPUok = accelgyro.testConnection();
  Serial.println(MPUok ? F("MPU6050 conectado com sucesso!") : F("Falha ao conectar com MPU6050"));

  Serial.println("Atualizando deslocamento interno do sensor...");
  // -76	-2359	1688	0	0	0
  /*Serial.print(accelgyro.getXAccelOffset()); Serial.print("\t"); // -76
  Serial.print(accelgyro.getYAccelOffset()); Serial.print("\t"); // -2359
  Serial.print(accelgyro.getZAccelOffset()); Serial.print("\t"); // 1688
  Serial.print(accelgyro.getXGyroOffset()); Serial.print("\t"); // 0
  Serial.print(accelgyro.getYGyroOffset()); Serial.print("\t"); // 0
  Serial.print(accelgyro.getZGyroOffset()); Serial.print("\t"); // 0
  Serial.print("\n");*/
  accelgyro.setXAccelOffset(-3274);
  accelgyro.setYAccelOffset(2404);
  accelgyro.setZAccelOffset(3148);
  accelgyro.setXGyroOffset(77);
  accelgyro.setYGyroOffset(-29);
  accelgyro.setZGyroOffset(29);
  /*Serial.print(accelgyro.getXAccelOffset()); Serial.print("\t"); // -76
  Serial.print(accelgyro.getYAccelOffset()); Serial.print("\t"); // -2359
  Serial.print(accelgyro.getZAccelOffset()); Serial.print("\t"); // 1688
  Serial.print(accelgyro.getXGyroOffset()); Serial.print("\t"); // 0
  Serial.print(accelgyro.getYGyroOffset()); Serial.print("\t"); // 0
  Serial.print(accelgyro.getZGyroOffset()); Serial.print("\t"); // 0
  Serial.print("\n");*/
  
  wdt_enable(WDTO_4S);
  
  servosOmbroE.attach(ServosOmbroE_Porta);
  servosBracoE.attach(ServosBracoE_Porta);
  servosCotoveloE.attach(ServosCotoveloE_Porta);
  servosOmbroD.attach(ServosOmbroD_Porta);
  servosBracoD.attach(ServosBracoD_Porta);
  servosCotoveloD.attach(ServosCotoveloD_Porta);
  //pinMode(LED_Porta, OUTPUT);
}

#include "equilibrio.h"
#include "transmissao.h"

void loop() {
  // put your main code here, to run repeatedly:
  
  if((millis()%Delay_LeituraAnalogica) == 0) {
    if(Escravo_Ligado == 1)
      leitura_analogica = analogRead(Reset_Porta);
    else
      leitura_analogica = 1024;
    //Serial.println(leitura_analogica);
    
    if(Botoes_Ligado == 1) {
      if(analogRead(BTN1_Porta) < NivelBaixo) {
        switch(comando) {
          case 0:
            comando = 1;
            break;
            
          case 1:
            comando = 0;
            break;
            
          case 2:
            comando = 1;
            break;
            
          default:
            comando = 0;
        }
      } else if(analogRead(BTN2_Porta) < NivelBaixo) {
        switch(comando) {
          case 2:
            comando = 0;
            break;
            
          default:
            comando = 2;
        }
      }
        
    }
  }
  
  if(Remoto_Habilitado == 1) {
    Rx();
  
    if(segundos%Delay_Retransmissao == 0 && segundos != segundoTentativa && statusTranceiver > -1 && statusTranceiver <= Tentativas) {
      if(statusTranceiver < Tentativas)
        Tx();
      else {
        comando = 0;
        statusTranceiver++;
      }
      
      segundoTentativa = segundos;
    }
  }
  
  if(iniciando == -1 || leitura_analogica < NivelBaixo) {
    if(y == 100){
      iniciando = -1;
      sinal = -1;
      estado = 0;
      y = 200;
      segundos = 0;
      segundoTentativa = -1;
      autoPedalar = 0;
      autoParar = 0;
    }
    iniciando = configPernas(y);
    
    if(y == 200)
      y = 0;
    else if(y < 50)
      y++;
    else
      y = 100;
    
  } else if(estado != sinal) {
    Wire.beginTransmission(1); // transmit to device #1
      Wire.write(estado);
    Wire.endTransmission();
    
    statusTranceiver = -1;
    
    Serial.print("Estado: ");
    Serial.println(estado);
    Serial.print("Comando: ");
    Serial.print(comando);
    
    if(Remoto_Habilitado == 1) {
      Serial.print(" - Status: ");
      Tx();
    } else
      Serial.println();
    
    sinal = estado;
  } else {
    Modo();
    
    switch(estado) {
      case 0:
        //digitalWrite(LED_Porta, LOW);
        if((millis()%Delay_Acelerometro) == 0) {
          Equilibrio();
        
        } else if((leitura_serial == 'T') || (leitura_serial == 't')) {
          estado = 2;
        }
        
        if(autoPedalar == 1) {
          if(segundos >= Timer_ON) {
            ciclo = -1;
            estado = 1;
            autoPedalar = 0;
            segundos = 0;
          }
        }
        break;
    
      case 1:
        //digitalWrite(LED_Porta, HIGH);
        if((millis()%Delay_Acelerometro) == 0) {
          Equilibrio();
        }
          
        ciclo++;
        
        if(autoParar == 1) {
          if(segundos >= Timer_OFF) {
            estado = 0;
            autoParar = 0;
          }
        }
        break;
      
      case 2:
        if((millis()%Delay_Acelerometro) == 0) Acelerometro();
        
        if(ciclo == 0) {
          posOmbroE = ServosOmbroE_Meio;
          posBracoE = ServosBracoE_Meio;
          posCotoveloE = ServosCotoveloE_Meio;
          posOmbroD = ServosOmbroD_Meio;
          posBracoD = ServosBracoD_Meio;
          posCotoveloD = ServosCotoveloD_Meio;
          Mexer_Bracos();
        }
        
        ciclo++;
        
        if((Delay_Tchau%ciclo) == 0) {
          Tchau();
          Mexer_Bracos();
        } break;
      
      case 3:
        Parada_Emergencia();
        break;
      
      default:
        estado = 0;
    }
    
    segundos = millis()/1000;
    
    if(segundos >= 86400) {
      segundos = 0;
    }
        
    if(ciclo >= Ciclos_Ref) {
      ciclo = 1;
    }
    
    delay(1);
  }
  
  wdt_reset();
}

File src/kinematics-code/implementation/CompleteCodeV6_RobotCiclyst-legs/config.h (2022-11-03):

#define Reset_Porta 1 // 0 = Leitura Analógica / 1 = Porta Reset

// Parâmetros de habilitação/desabilitação e ajustes de membros e procedimentos
int PernaE_Habilitada = -1;
int PernaD_Habilitada = -1;
int Pedalar_Ligado = -1;

// Parâmetros de configuração de servos e funções
int Tipo_Pedalada = -1;
int SentidoCoxas_Iguais = -1;
int SentidoJoelhos_Iguais = -1;
int SentidoTornozelos_Iguais = -1;

// Regulagem do desvio dos servos das pernas para ajustes finos rápidos
int QuadrilE_Desvio = -1;
int QuadrilD_Desvio = -1;
int CoxaE_Desvio = -1;
int CoxaD_Desvio = -1;
int JoelhoE_Desvio = -1;
int JoelhoD_Desvio = -1;
int TornozeloE_Desvio = -1;
int TornozeloD_Desvio = -1;

// Ajustes de Movimento
int Altura_Ajuste = -1;
int InicioPedalada_CoxaE = -1;
int InicioPedalada_JoelhoE = -1;
int InicioPedalada_TornozeloE = -1;
int InicioPedalada_CoxaD = -1;
int InicioPedalada_JoelhoD = -1;
int InicioPedalada_TornozeloD = -1;

// Referências de funções, para os motores conseguirem efetuar o movimento esperado
int Delay_Servos_Max = -1;
int Delay_Servos_Min = -1;
int Delay_Servos = -1;
int Delay_Servos_Taxa = -1;
int Delay_Pausa = -1;
int Delay_Quadril = -1;
int Delay_Ajuste = -1;
int TaxaMax_Ref = -1;
int TaxaMin_Ref = -1;
int Taxa_Ref = -1;

// Constantes de ângulos cujo o robô vá para a posição de parado
int Parada_QuadrilE = -1;
int Parada_CoxaE = -1;
int Parada_JoelhoE = -1;
int Parada_TornozeloE = -1;
int Parada_QuadrilD = -1;
int Parada_CoxaD = -1;
int Parada_JoelhoD = -1;
int Parada_TornozeloD = -1;

// Atribuição de portas digitais aos dispositivos
#define ServoQuadrilE_Porta        3
#define ServoCoxaE_Porta           4
#define ServoJoelhoE_Porta         5
#define ServoTornozeloE_Porta      6
#define ServoQuadrilD_Porta        7
#define ServoCoxaD_Porta           8
#define ServoJoelhoD_Porta         9
#define ServoTornozeloD_Porta      10
#define Reset_Porta                12
#define LED_Porta                  13

// Parâmetros de limites dos servos motores com angulação total disponível
int Servos_Pos_Max = -1;
int Servos_Pos_Min = -1;

// Parâmetros de limites dos servos motores com angulação limitada por peças e/ou espaço
int ServoQuadrilE_Pos_Max = -1;
int ServoQuadrilE_Pos_Min = -1;
int ServoQuadrilD_Pos_Max = -1;
int ServoQuadrilD_Pos_Min = -1;

// Parâmetros literais de desvio dos servos das pernas
int Servos_Raio_Ref = -1;
int ServosQuadris_Raio = -1;
int ServoQuadrilE_Meio = -1;
int ServoQuadrilD_Meio = -1;
int ServosCoxas_Raio = -1;
int ServoCoxaE_Meio = -1;
int ServoCoxaD_Meio = -1;
float TaxaCoxas_Ref = 0;
int ServosJoelhos_Raio = -1;
int ServoJoelhoE_Meio = -1;
int ServoJoelhoD_Meio = -1;
float TaxaJoelhos_Ref = 0;
int ServosTornozelos_Raio = -1;
int ServoTornozeloE_Meio = -1;
int ServoTornozeloD_Meio = -1;
float TaxaTornozelos_Ref = 0;

//#define LED_OnBoard 13 // (Arduino is 13, Teensy is 11, Teensy++ is 6)
bool blinkState = false;

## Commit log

2022-11-03 adding basic files
    [ACRILICO_JOELHO.stl, ANTEBRACO.stl, BASE_COTOVELO.stl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]
2022-11-03 rename files
    [ACRYLIC_KNEE.stl, BACK.stl, BASE_ELBOW.stl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]
